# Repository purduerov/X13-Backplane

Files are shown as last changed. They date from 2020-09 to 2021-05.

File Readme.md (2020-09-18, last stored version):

# Readme for X13-Backplane

Whenever you make a new part, download the datasheet and save it here _**and**_ with the part in the parts library

Always pull other people's changes before beginning to work
`git pull`

Be sure to push your changes after  working on them. Run:
1. `git add .` to add any files in this directory or a subdirectory
or `git add -u` to add any modified files
2. (Optional) `git clean -nX` to see what ignored files can be removed
	`git clean -fX` removes ignored files (Eagle backups)
3. `git commit -m "helpful commit message"` with a description of the work that you did
4. `git push` to push your work to github

Other helpful commands
* `git status` says information about modified and staged files
* `git log` shows the recent commits of the repository
* `git log filename.extension` show the recent commits for just that file
* `git checkout first-couple-letter-of-commit-id` lets you go back to a previous version
* `git checkout master` brings you back to the latest commit
* `git tag` lists the tags
* `git tag -a orderX -m "the version of the board placed for the X'th order"` tag a specific commit
* `git push --tags` needed to push tags to remote
* `git show orderX` show the commit log for the given tag
* `git checkout orderX` go back and interact with the files at the tagged commit

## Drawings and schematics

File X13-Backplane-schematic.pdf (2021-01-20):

A

A

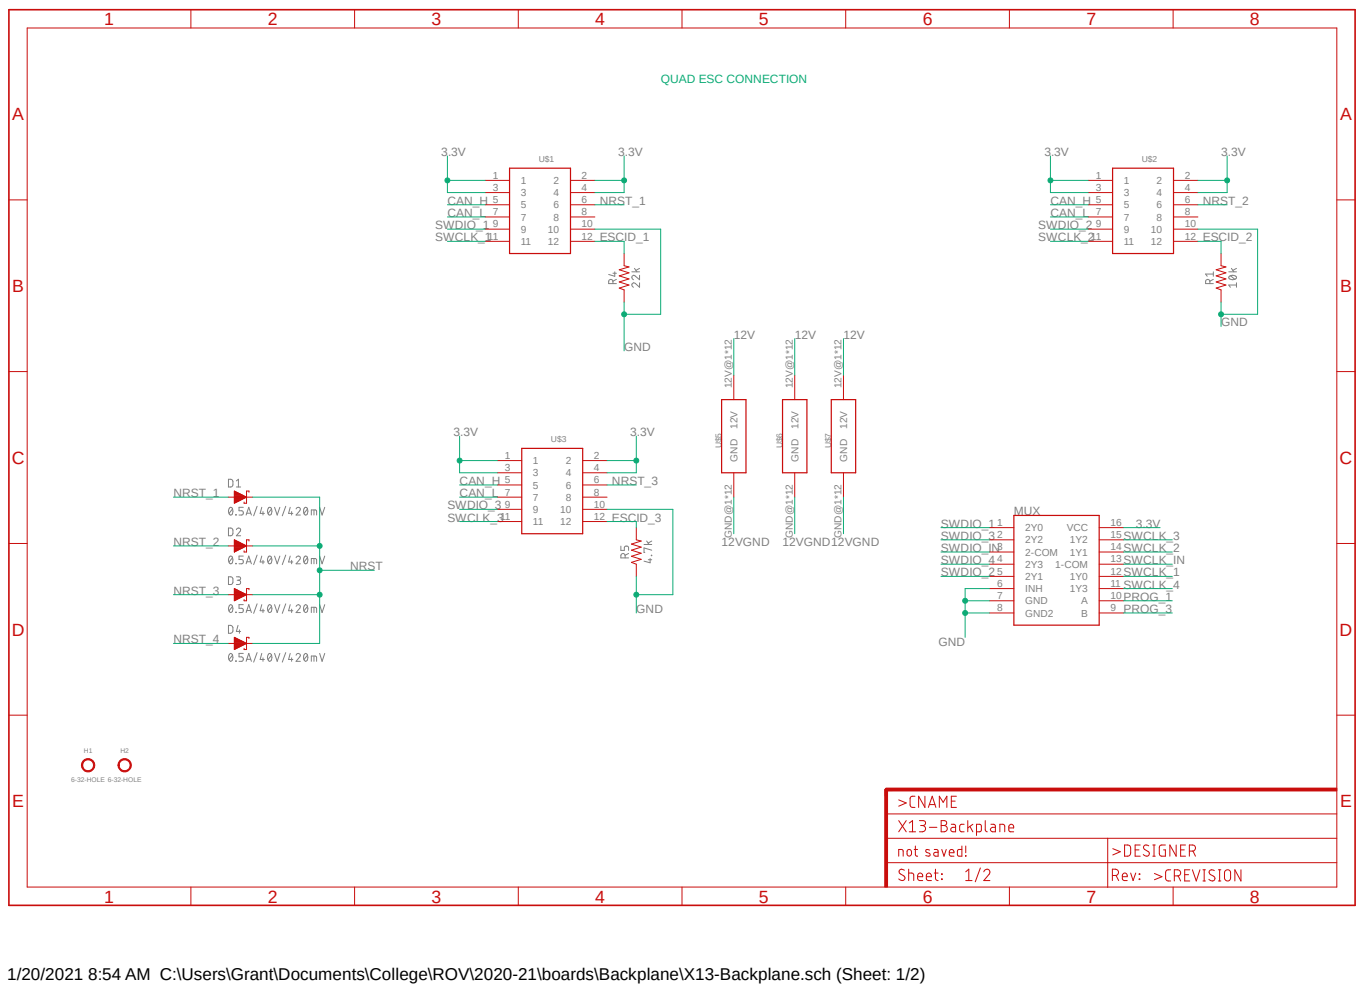
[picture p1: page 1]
2Y0 1 2Y2 2 2-COM 3 2Y3 4 2Y1 5 INH 6 GND 7; GND2 8; 12 1-COM; 15 VCC; 16 MUX; 6-32-HOLE; 12V ¹²V@¹*12 GND GND@¹*12 U$5; 12V ¹²V@¹*12 GND GND@¹*12 U$6; 12V ¹²V@¹*12 GND GND@¹*12 U$7; PROG_1; PROG_3; SWDIO_1; SWCLK_1; GND; SWDIO_3; SWDIO_2; SWCLK_2; SWCLK_3; CAN_H; CAN_L; SWCLK_IN; SWDIO_IN; NRST; ESCID_1; ESCID_2; ESCID_3; 12VGND 12VGND12VGND; NRST_1; NRST_2; NRST_3; NRST_4; SWDIO_4; SWCLK_4

QUAD ESC CONNECTION

1/20/2021 8:54 AM C:\Users\Grant\Documents\College\ROV\2020-21\boards\Backplane\X13-Backplane.sch (Sheet: 1/2)

# 8 J8

A

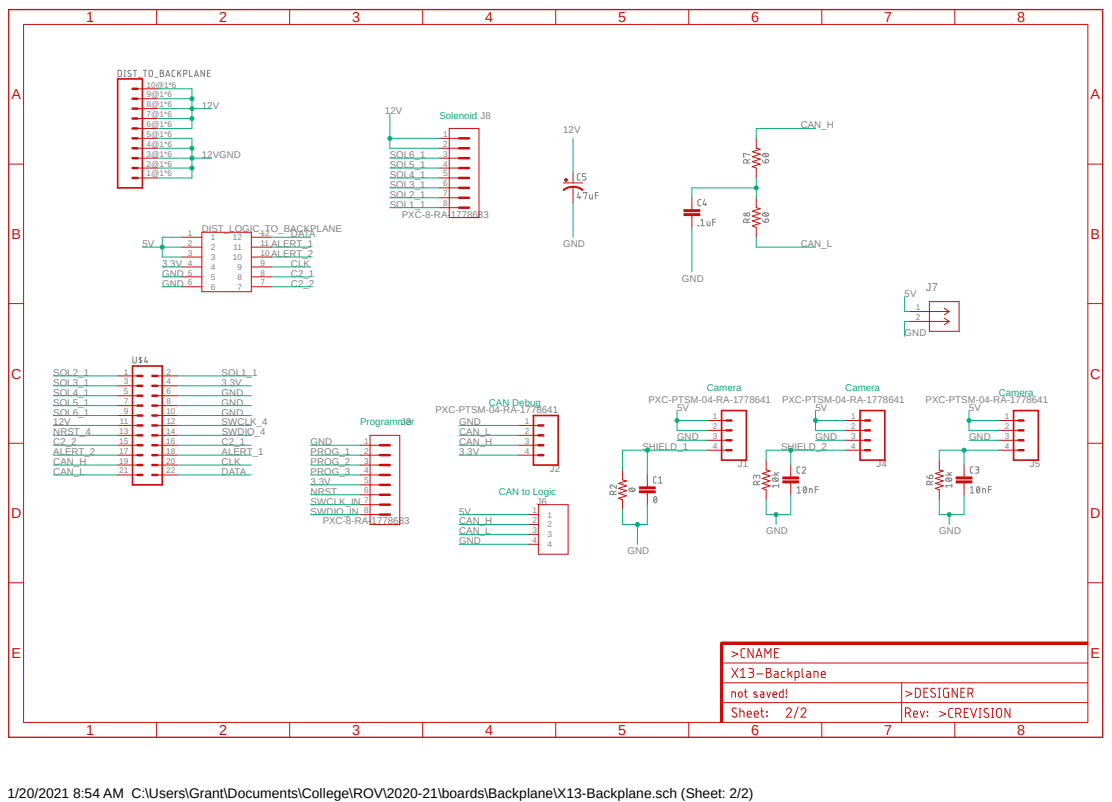
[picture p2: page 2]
PXC-8-RA-1778683; PXC-PTSM-04-RA-1778641; 12 DIST_LOGIC_TO_BACKPLANE; PROG_1; PROG_3; GND; GND GND; CAN_H; CAN_L; SWCLK_IN SWDIO_IN; PROG_2; NRST; ALERT_1; ALERT_2; CLK; DATA; SOL2_1; SOL3_1; SOL4_1; SOL5_1; SOL6_1; SOL1_1; SHIELD_1; SHIELD_2; 12VGND; NRST_4; SWDIO_4; SWCLK_4; CAN Debug; Programmer; Camera; Solenoid

PXC-PTSM-04-RA-1778641

CAN to Logic

1/20/2021 8:54 AM C:\Users\Grant\Documents\College\ROV\2020-21\boards\Backplane\X13-Backplane.sch (Sheet: 2/2)

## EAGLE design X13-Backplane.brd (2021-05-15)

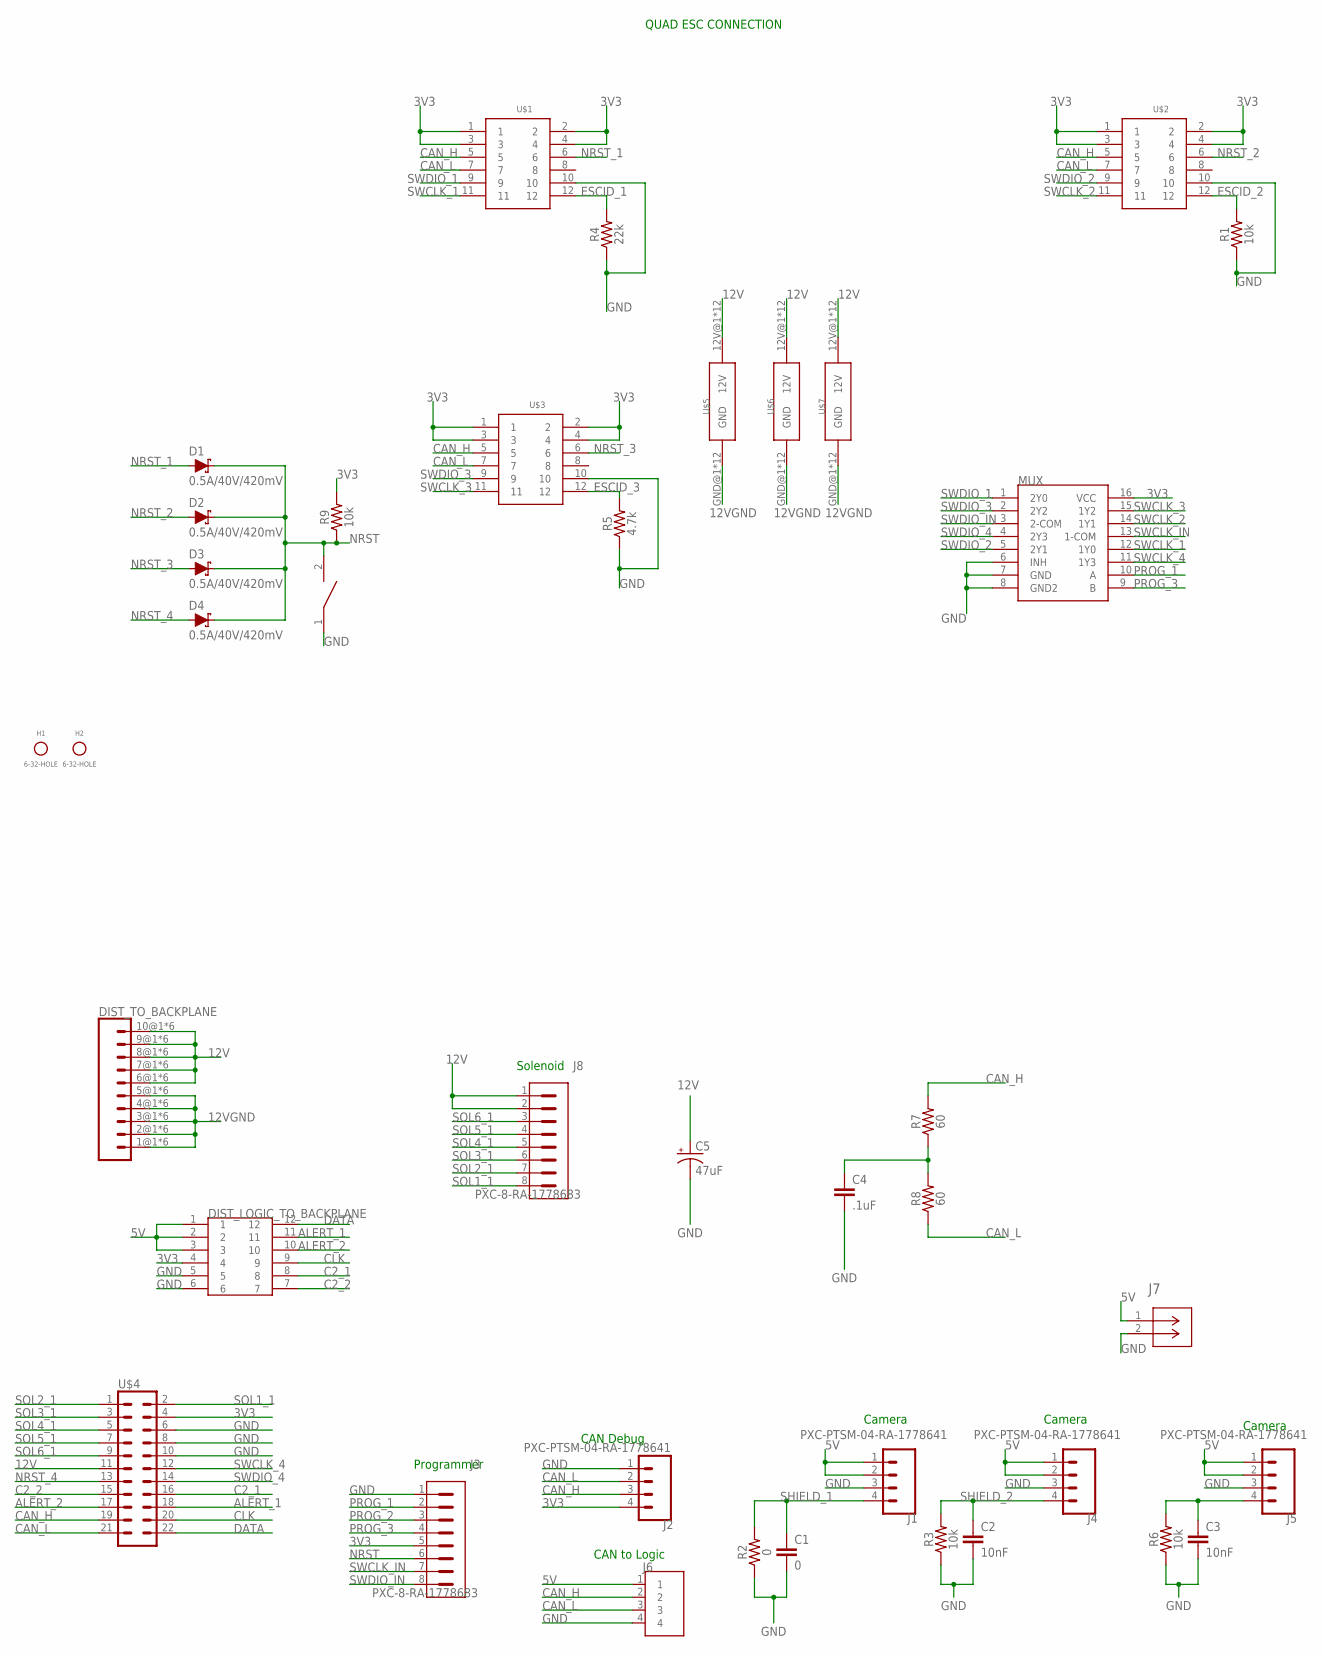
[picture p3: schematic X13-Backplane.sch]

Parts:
C1: 0; 0603
C2, C3: 10nF; 0603
C4: .1uF; 0603
C5: 47uF; PANASONIC_D
D1, D2, D3, D4: 0.5A/40V/420mV; SOD-323
DIST_LOGIC_TO_BACKPLANE: IPL1-106-01-L-D-K
DIST_TO_BACKPLANE: MPPT-10-01-01-L-RA-SD
H1, H2: 6-32-HOLE
J1, J2, J4, J5: PXC-PTSM-04-RA-1778641
J3, J8: PXC-8-RA-1778683
J6: 284512-4; TE_284512-4
J7: POE_TERMINAL; CONN2_282834-2_TEC
MUX: TI-SN74LV4052A; SOIC-16
R1, R3, R6, R9: 10k; 0603
R2: 0; 0603
R4: 22k; 0603
R5: 4.7k; 0603
R7, R8: 60; 0603
U$1, U$2, U$3: BACKPLANE_CONNECTORSBKP; BACKPLANE_CONNECTORS_BKP
U$4: BKP-TO-SOL; BKP-TO-SOL_TMM-111-01-T-D
U$5, U$6, U$7: BACKPLANE_ESC_ADAPTER_PWRBKP; BACKPLANE_ESC_ADAPTER_BKP_PWR
U$8: DISCRETECOMPONENTS_SWITCH; DISCRETECOMPONENTS_SW_2512

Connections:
3V3: DIST_LOGIC_TO_BACKPLANE.4, J2.4, J3.5, MUX.16 (VCC), R9.2, U$1.1, U$1.2, U$1.3, U$1.4, U$2.1, U$2.2, U$2.3, U$2.4, U$3.1, U$3.2, U$3.3, U$3.4, U$4.4
5V: DIST_LOGIC_TO_BACKPLANE.1, DIST_LOGIC_TO_BACKPLANE.2, DIST_LOGIC_TO_BACKPLANE.3, J1.1, J1.2, J4.1, J4.2, J5.1, J5.2, J6.1, J7.1
12V: C5.+, DIST_TO_BACKPLANE.6@1 (6), DIST_TO_BACKPLANE.6@2 (6), DIST_TO_BACKPLANE.6@3 (6), DIST_TO_BACKPLANE.6@4 (6), DIST_TO_BACKPLANE.6@5 (6), DIST_TO_BACKPLANE.6@6 (6), DIST_TO_BACKPLANE.7@1 (7), DIST_TO_BACKPLANE.7@2 (7), DIST_TO_BACKPLANE.7@3 (7), DIST_TO_BACKPLANE.7@4 (7), DIST_TO_BACKPLANE.7@5 (7), DIST_TO_BACKPLANE.7@6 (7), DIST_TO_BACKPLANE.8@1 (8), DIST_TO_BACKPLANE.8@2 (8), DIST_TO_BACKPLANE.8@3 (8), DIST_TO_BACKPLANE.8@4 (8), DIST_TO_BACKPLANE.8@5 (8), DIST_TO_BACKPLANE.8@6 (8), DIST_TO_BACKPLANE.9@1 (9), DIST_TO_BACKPLANE.9@2 (9), DIST_TO_BACKPLANE.9@3 (9), DIST_TO_BACKPLANE.9@4 (9), DIST_TO_BACKPLANE.9@5 (9), DIST_TO_BACKPLANE.9@6 (9), DIST_TO_BACKPLANE.10@1 (10), DIST_TO_BACKPLANE.10@2 (10), DIST_TO_BACKPLANE.10@3 (10), DIST_TO_BACKPLANE.10@4 (10), DIST_TO_BACKPLANE.10@5 (10), DIST_TO_BACKPLANE.10@6 (10), J8.1, J8.2, U$4.11, U$5.12V@1 (12V), U$5.12V@2 (12V), U$5.12V@3 (12V), U$5.12V@4 (12V), U$5.12V@5 (12V), U$5.12V@6 (12V), U$5.12V@7 (12V), U$5.12V@8 (12V), U$5.12V@9 (12V), U$5.12V@10 (12V), U$5.12V@11 (12V), U$5.12V@12 (12V), U$6.12V@1 (12V), U$6.12V@2 (12V), U$6.12V@3 (12V), U$6.12V@4 (12V), U$6.12V@5 (12V), U$6.12V@6 (12V), U$6.12V@7 (12V), U$6.12V@8 (12V), U$6.12V@9 (12V), U$6.12V@10 (12V), U$6.12V@11 (12V), U$6.12V@12 (12V), U$7.12V@1 (12V), U$7.12V@2 (12V), U$7.12V@3 (12V), U$7.12V@4 (12V), U$7.12V@5 (12V), U$7.12V@6 (12V), U$7.12V@7 (12V), U$7.12V@8 (12V), U$7.12V@9 (12V), U$7.12V@10 (12V), U$7.12V@11 (12V), U$7.12V@12 (12V)
12VGND: DIST_TO_BACKPLANE.1@1 (1), DIST_TO_BACKPLANE.1@2 (1), DIST_TO_BACKPLANE.1@3 (1), DIST_TO_BACKPLANE.1@4 (1), DIST_TO_BACKPLANE.1@5 (1), DIST_TO_BACKPLANE.1@6 (1), DIST_TO_BACKPLANE.2@1 (2), DIST_TO_BACKPLANE.2@2 (2), DIST_TO_BACKPLANE.2@3 (2), DIST_TO_BACKPLANE.2@4 (2), DIST_TO_BACKPLANE.2@5 (2), DIST_TO_BACKPLANE.2@6 (2), DIST_TO_BACKPLANE.3@1 (3), DIST_TO_BACKPLANE.3@2 (3), DIST_TO_BACKPLANE.3@3 (3), DIST_TO_BACKPLANE.3@4 (3), DIST_TO_BACKPLANE.3@5 (3), DIST_TO_BACKPLANE.3@6 (3), DIST_TO_BACKPLANE.4@1 (4), DIST_TO_BACKPLANE.4@2 (4), DIST_TO_BACKPLANE.4@3 (4), DIST_TO_BACKPLANE.4@4 (4), DIST_TO_BACKPLANE.4@5 (4), DIST_TO_BACKPLANE.4@6 (4), DIST_TO_BACKPLANE.5@1 (5), DIST_TO_BACKPLANE.5@2 (5), DIST_TO_BACKPLANE.5@3 (5), DIST_TO_BACKPLANE.5@4 (5), DIST_TO_BACKPLANE.5@5 (5), DIST_TO_BACKPLANE.5@6 (5), U$5.GND@1 (GND), U$5.GND@2 (GND), U$5.GND@3 (GND), U$5.GND@4 (GND), U$5.GND@5 (GND), U$5.GND@6 (GND), U$5.GND@7 (GND), U$5.GND@8 (GND), U$5.GND@9 (GND), U$5.GND@10 (GND), U$5.GND@11 (GND), U$5.GND@12 (GND), U$6.GND@1 (GND), U$6.GND@2 (GND), U$6.GND@3 (GND), U$6.GND@4 (GND), U$6.GND@5 (GND), U$6.GND@6 (GND), U$6.GND@7 (GND), U$6.GND@8 (GND), U$6.GND@9 (GND), U$6.GND@10 (GND), U$6.GND@11 (GND), U$6.GND@12 (GND), U$7.GND@1 (GND), U$7.GND@2 (GND), U$7.GND@3 (GND), U$7.GND@4 (GND), U$7.GND@5 (GND), U$7.GND@6 (GND), U$7.GND@7 (GND), U$7.GND@8 (GND), U$7.GND@9 (GND), U$7.GND@10 (GND), U$7.GND@11 (GND), U$7.GND@12 (GND)
ALERT_1: DIST_LOGIC_TO_BACKPLANE.11, U$4.18
ALERT_2: DIST_LOGIC_TO_BACKPLANE.10, U$4.17
C2_1: DIST_LOGIC_TO_BACKPLANE.8, U$4.16
C2_2: DIST_LOGIC_TO_BACKPLANE.7, U$4.15
CAN_H: J2.3, J6.2, R7.2, U$1.5, U$2.5, U$3.5, U$4.19
CAN_L: J2.2, J6.3, R8.1, U$1.7, U$2.7, U$3.7, U$4.21
CLK: DIST_LOGIC_TO_BACKPLANE.9, U$4.20
DATA: DIST_LOGIC_TO_BACKPLANE.12, U$4.22
ESCID_1: R4.2, U$1.12
ESCID_2: R1.2, U$2.12
ESCID_3: R5.2, U$3.12
GND: C1.2, C2.2, C3.2, C4.2, C5.-, DIST_LOGIC_TO_BACKPLANE.5, DIST_LOGIC_TO_BACKPLANE.6, J1.3, J2.1, J3.1, J4.3, J5.3, J6.4, J7.2, MUX.6 (INH), MUX.7 (GND), MUX.8 (GND2), R1.1, R2.1, R3.1, R4.1, R5.1, R6.1, U$1.10, U$2.10, U$3.10, U$4.6, U$4.8, U$4.10, U$8.1
unnamed: C4.1, R7.1, R8.2
NRST: D1.C, D2.C, D3.C, D4.C, J3.6, R9.1, U$8.2
NRST_1: D1.A, U$1.6
NRST_2: D2.A, U$2.6
NRST_3: D3.A, U$3.6
NRST_4: D4.A, U$4.13
PROG_1: J3.2, MUX.10 (A)
PROG_2: J3.3
PROG_3: J3.4, MUX.9 (B)
SHIELD_1: C1.1, J1.4, R2.2
SHIELD_2: C2.1, J4.4, R3.2
SHIELD_3: C3.1, J5.4, R6.2
SOL1_1: J8.8, U$4.2
SOL2_1: J8.7, U$4.1
SOL3_1: J8.6, U$4.3
SOL4_1: J8.5, U$4.5
SOL5_1: J8.4, U$4.7
SOL6_1: J8.3, U$4.9
SWCLK_1: MUX.12 (1Y0), U$1.11
SWCLK_2: MUX.14 (1Y1), U$2.11
SWCLK_3: MUX.15 (1Y2), U$3.11
SWCLK_4: MUX.11 (1Y3), U$4.12
SWCLK_IN: J3.7, MUX.13 (1-COM)
SWDIO_1: MUX.1 (2Y0), U$1.9
SWDIO_2: MUX.5 (2Y1), U$2.9
SWDIO_3: MUX.2 (2Y2), U$3.9
SWDIO_4: MUX.4 (2Y3), U$4.14
SWDIO_IN: J3.8, MUX.3 (2-COM)

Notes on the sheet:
CAN to Logic
CAN Debug
Programmer
QUAD ESC CONNECTION
Camera
Solenoid

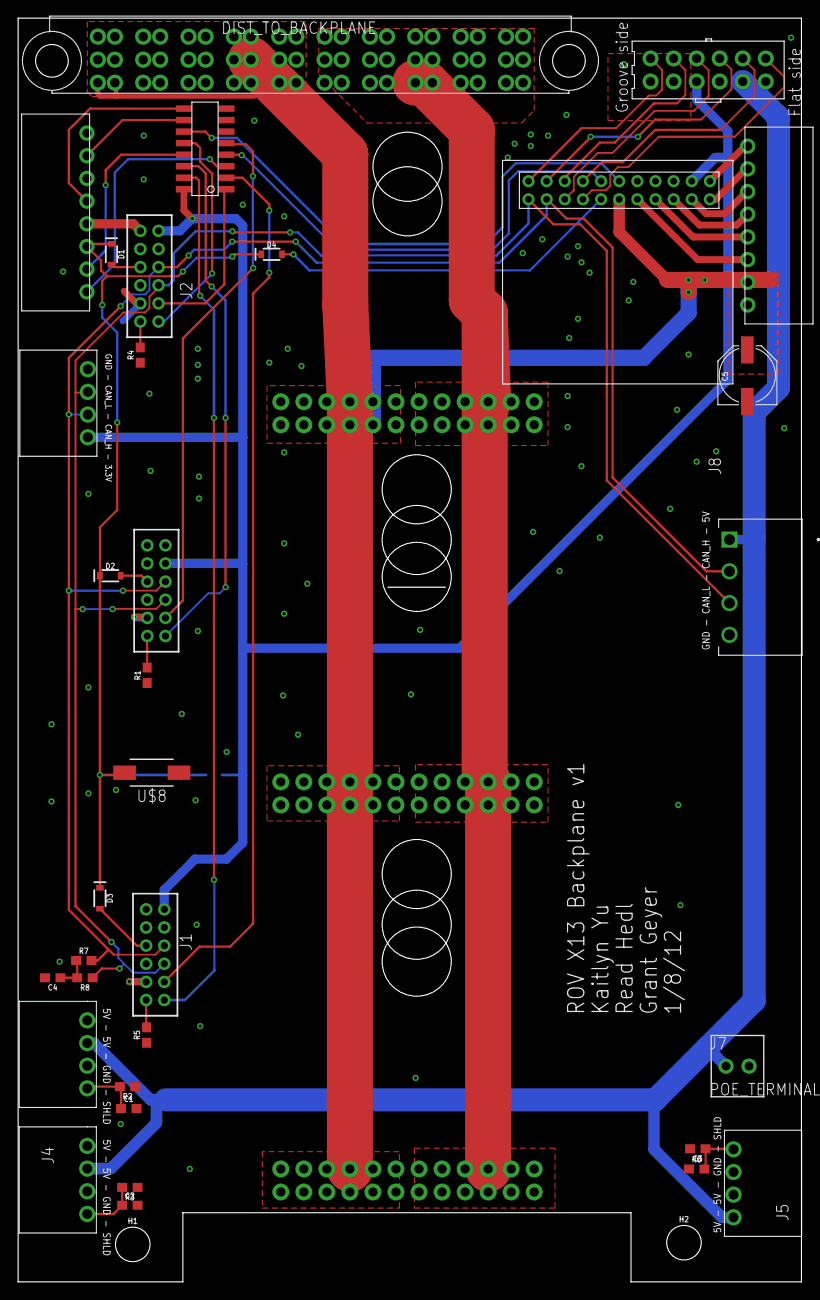
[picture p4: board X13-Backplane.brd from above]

Board: 2 copper layers, 86.4 x 139.3 mm, 39 parts (1 on the bottom side), 43 nets.

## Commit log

2020-10-21 first push
    [X13-Backplane.brd, X13-Backplane.sch]
2020-10-21 Updated Solenoid Board
    [X13-Backplane.brd, X13-Backplane.sch]
2020-10-24 added Thrusters/motor connectors + QuadESC Connectors
    [X13-Backplane.brd, X13-Backplane.sch]
2020-10-31 Design review changes-2
    [X13-Backplane.brd, X13-Backplane.sch]
2020-10-31 added LED resistor values
    [X13-Backplane.brd, X13-Backplane.sch]
2020-11-01 board dimension
    [X13-Backplane.brd, X13-Backplane.sch]
2020-11-14 draft board layout- missing power connector
    [X13-Backplane.brd, X13-Backplane.sch]
2020-11-14 added back solenoid board
    [X13-Backplane.brd, X13-Backplane.sch]
2020-11-14 removed solenoid board
    [X13-Backplane.brd, X13-Backplane.sch]
2020-12-05 updated schematic
    [X13-Backplane.brd, X13-Backplane.sch]
2020-12-05 wired board
    [X13-Backplane.brd, X13-Backplane.sch]
2020-12-06 updated solenoid connector
    [X13-Backplane.brd, X13-Backplane.sch]
2020-12-06 updated polygonsr
    [X13-Backplane.brd]
2020-12-06 updated via's
    [X13-Backplane.brd]
2020-12-06 updated mux
    [X13-Backplane.brd, X13-Backplane.sch]
2020-12-06 updated 5v trace
    [X13-Backplane.brd]
2021-01-03 updated spacing on parts
    [X13-Backplane.brd]
2021-01-05 Placed Solenoid Connector and schematic pinout
    [X13-Backplane.brd, X13-Backplane.sch]
2021-01-08 updated board layout and connections
    [X13-Backplane.brd, X13-Backplane.sch]
2021-01-08 updated board
    [X13-Backplane.brd, X13-Backplane.sch]
2021-01-08 added swclk/swdio signals to solenoid board
    [X13-Backplane.brd, X13-Backplane.sch]
2021-01-08 added cutouts, adjusted gnd
    [X13-Backplane.brd, X13-Backplane.sch]
2021-01-09 Added third cutout and models for te 4 pin conn
    [X13-Backplane.brd, X13-Backplane.sch]
2021-01-09 add tStop polygon
    [X13-Backplane.brd]
2021-01-09 OPE. GND connections were missing on esc controller connector
    [X13-Backplane.brd, X13-Backplane.sch]
2021-01-09 cleaned up traces
    [X13-Backplane.brd]
2021-01-10 Schematic PDF and step
2021-01-11 moved 2x6 logic dist block in and add conn for switch as backup
    [X13-Backplane.brd, X13-Backplane.sch]
2021-01-12 re-add soldermask around connectors to adapter board
    [X13-Backplane.brd]
2021-01-20 Fixed misprinting of schematic
2021-05-03 Add reset switch for all micros, move connectors in
    [X13-Backplane.brd, X13-Backplane.sch]
2021-05-04 Place resistor. Move solenoid connector in
    [X13-Backplane.brd]
2021-05-15 Change dimension to holes for ESC wires
    [X13-Backplane.brd]

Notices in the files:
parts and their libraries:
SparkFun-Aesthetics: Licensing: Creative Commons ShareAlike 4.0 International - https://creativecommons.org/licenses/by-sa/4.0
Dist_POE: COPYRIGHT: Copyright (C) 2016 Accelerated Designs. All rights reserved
